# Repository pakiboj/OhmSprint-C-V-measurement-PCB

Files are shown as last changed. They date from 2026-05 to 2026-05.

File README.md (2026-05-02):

# OhmSprint-C-V-measurement-PCB

# SRB
PCB naprvljen za potrebe studentskog takmicenja OhmSprint organizovanog u aprilu 2026. godine. Bilo je potrebno napraviti uredjaj za merenje struje i napona radi estimiranja potrosnje, pa potom date podatke slati na neki nacin korisniku. 

Za potrebe projekta izabran je ESP32-C2 mikrokontroler a merenje struje i napona radjeno je preko ATM90E26 mernog cipa. Slanje podataka uradjeno je pomocu WROOM-C2 cipa ugradjenog sa ESP kontrolerom. 

# ENG
PCB designed for the needs of the student competition OhmSprint, organized in April 2026. The task was to build a device for measuring current and voltage in order to estimate power consumption, and then transmit the collected data to the user in some way.

For the purposes of the project, an ESP32-C2 microcontroller was chosen, and current and voltage measurements were performed via the ATM90E26 metering chip. Data transmission was implemented using the WROOM-C2 chip integrated with the ESP controller.

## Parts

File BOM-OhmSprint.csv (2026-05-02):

Reference | Qty | Exclude from BOM | Exclude from Board | Datasheet | Footprint | Value | MANUFACTURER | MPN | link
C1,C7,C8,C19,C26 | 5 |  |  | ~ | Capacitor_SMD:C_0603_1608Metric | 100n | NextGen Components | 0603B104K250SD | https://www.digikey.com/en/products/detail/nextgen-components/0603B104K250SD/22601930
C2 | 1 |  |  | ~ | Capacitor_SMD:C_0603_1608Metric | 22n | NextGen Components | 0603B223K500SD | https://www.digikey.com/en/products/detail/nextgen-components/0603B223K500SD/22601916
C3 | 1 |  |  |  | Capacitor_SMD:C_0805_2012Metric | 4.7uF | NextGen Components | 0805B475K250CC | https://www.digikey.com/en/products/detail/nextgen-components/0805B475K250CC/22601895
C4,C18 | 2 |  |  |  | Capacitor_SMD:C_0805_2012Metric | 0.1uF | NextGen Components | 0805B104J500BD | https://www.digikey.com/en/products/detail/nextgen-components/0805B104J500BD/22601900
C5,C11,C16,C25 | 4 |  |  | ~ | Capacitor_SMD:C_0805_2012Metric | 1u | Aillen | 0805B105K250CC | https://www.digikey.com/en/products/detail/nextgen-components/0805B105K250CC/22081490
C6 | 1 |  |  | ~ | Capacitor_SMD:C_0805_2012Metric | 220n | NextGen Components | 0805B224K500CC | https://www.digikey.com/en/products/detail/nextgen-components/0805B224K500CC/22601952
C9,C10 | 2 |  |  | ~ | Capacitor_SMD:C_0603_1608Metric | 20p | NextGen Components | 0603N200J500SD | https://www.digikey.com/en/products/detail/nextgen-components/0603N200J500SD/22601914
C15,C16-2,C20,C21 | 4 |  |  |  | Capacitor_SMD:C_0805_2012Metric | 33nF | NextGen Components | 0805B333K500BD | https://www.digikey.com/en/products/detail/nextgen-components/0805B333K500BD/22601891
C16-1,C17 | 2 |  |  |  | Capacitor_SMD:C_0603_1608Metric | 330nF | NextGen Components | 0805B334K500CC | https://www.digikey.com/en/products/detail/nextgen-components/0805B334K500CC/22601908
C22 | 1 |  |  |  | Capacitor_SMD:C_0805_2012Metric | 10uF | NextGen Components | 0805B334K500CC | https://www.digikey.com/en/products/detail/nextgen-components/0805B334K500CC/22601908
C23,C24 | 2 |  |  |  | Capacitor_SMD:C_0603_1608Metric | 0.1uF | NextGen Components | 0603B104K250SD | https://www.digikey.com/en/products/detail/nextgen-components/0603B104K250SD/22601930
D1,D2,D3 | 3 |  |  | ~ | Diode_SMD:D_1206_3216Metric | LED | XINGLIGHT | XL-3216SURC | https://www.digikey.com/en/products/detail/xinglight/XL-3216SURC/25673079
FB2 | 1 |  |  | ~ | Inductor_SMD:L_0805_2012Metric | 120R | Laird-Signal Integrity Products | LI0805H121R-10 | https://www.digikey.com/en/products/detail/laird-signal-integrity-products/LI0805H121R-10/806621
H1,H2,H3,H4 | 4 | Excluded from BOM |  | ~ | MountingHole:MountingHole_2mm | MountingHole
J1,J2,J4,J11,J12,J18 | 6 |  |  | ~ | Connector_AMASS:AMASS_XT30U-F_1x02_P5.0mm_Vertical | Conn_01x02_Pin | Sullins Connector Solutions | PRPC002SAAN-RC | https://www.digikey.com/en/products/detail/sullins-connector-solutions/PRPC002SAAN-RC/2775252
J3 | 1 |  |  |  | OhmSprint:CUI_PJ-002AH-SMT-TR | PJ-002AH-SMT-TR | Same Sky (Formerly CUI Devices) | PJ-002AH-SMT-TR | https://www.digikey.com/en/products/detail/same-sky-formerly-cui-devices/PJ-002AH-SMT-TR/408452
J5,J6,J19,J20 | 4 |  |  | ~ | Connector:FanPinHeader_1x04_P2.54mm_Vertical | Conn_01x04_Pin | Amphenol ICC (FCI) | 68002-404HLF | https://www.digikey.com/en/products/detail/amphenol-cs-fci/68002-404HLF/1878460
J7 | 1 |  |  | SJ-3523-SMT | OhmSprint:SJ-3523-SMT_CUD | SJ-3523-SMT | Same Sky (Formerly CUI Devices) | SJ-3523-SMT-TR | https://www.digikey.com/en/products/detail/same-sky-formerly-cui-devices/SJ-3523-SMT-TR/281297
J8 | 1 |  |  | USB_C_Receptacle_USB2.0_16P | Connector_USB:USB_C_Receptacle_GCT_USB4105-xx-A_16P_TopMnt_Horizontal | USB_C_Receptacle_USB2.0_16P | Same Sky (Formerly CUI Devices) | UJ20-C-H-G-SMT-TR | https://www.digikey.com/en/products/detail/same-sky-formerly-cui-devices/UJ20-C-H-G-SMT-TR/16629796
J9,J10,J13 | 3 |  |  | ~ | Connector:FanPinHeader_1x03_P2.54mm_Vertical | Conn_01x03_Pin | Amphenol ICC (FCI) | 68001-203HLF | https://www.digikey.com/en/products/detail/amphenol-cs-fci/68001-203HLF/2023312
J14,J15,J16,J17 | 4 |  |  | ~ | Connector_Hirose:Hirose_DF63M-1P-3.96DSA_1x01_P3.96mm_Vertical | Conn_01x01_Pin | Amphenol ICC (FCI) | 68000-101HLF | https://www.digikey.com/en/products/detail/amphenol-cs-fci/68000-101HLF/2023311
L2 | 1 |  |  | ~ | Inductor_SMD:L_0805_2012Metric | 4u7 | Coilcraft | 0805LS-222XJRC | https://www.digikey.com/en/products/detail/coilcraft/0805LS-222XJRC/15794577
R1,R10 | 2 |  |  | ~ | Resistor_SMD:R_0805_2012Metric | 5k1 | Bourns Inc. | CR0805-JW-512ELF | https://www.digikey.com/en/products/detail/bourns-inc/CR0805-JW-512ELF/3785337
R3,R5,R6 | 3 |  |  | ~ | Resistor_SMD:R_0805_2012Metric | 100R | Bourns Inc. | CR0805-FX-1000ELF | https://www.digikey.com/en/products/detail/bourns-inc/CR0805-FX-1000ELF/3740946
R3-1,R7,R16 | 3 |  |  | ~ | Resistor_SMD:R_0805_2012Metric | 10k | Bourns Inc. | CR0805-FX-1002ELF | https://www.digikey.com/en/products/detail/bourns-inc/CR0805-FX-1002ELF/3593209
R4,R17 | 2 |  |  | ~ | Resistor_SMD:R_0805_2012Metric | 1k5 | Bourns Inc. | CR0805-JW-152ELF | https://www.digikey.com/en/products/detail/bourns-inc/CR0805-JW-152ELF/3785240
R8,R9,R11,R15,R19,R20,R28 | 7 |  |  | ~ | Resistor_SMD:R_0805_2012Metric | 1k | Bourns Inc. | CR0805-FX-1001ELF | https://www.digikey.com/en/products/detail/bourns-inc/CR0805-FX-1001ELF/3593162
R12,R13,R14 | 3 |  |  |  | Resistor_SMD:R_0805_2012Metric | 4k | Bourns Inc. | CR0805-FX-4021ELF | https://www.digikey.com/en/products/detail/bourns-inc/CR0805-FX-4021ELF/3784926
R18 | 1 |  |  | ~ | Resistor_SMD:R_0805_2012Metric | 88k7 | Bourns Inc. | CR0805-FX-1001ELF | https://www.digikey.com/en/products/detail/bourns-inc/CR0805-FX-1001ELF/3593162
R21 | 1 |  |  |  | Resistor_SMD:R_0805_2012Metric | 51R | Bourns Inc. | CR0805-FX-51R0ELF | https://www.digikey.com/en/products/detail/bourns-inc/CR0805-FX-51R0ELF/3785003
R22,R23,RC1,RC2 | 4 |  |  |  | Resistor_SMD:R_0805_2012Metric | 2R4 | Bourns Inc. | CR0805-FX-2401ELF | https://www.digikey.com/en/products/detail/bourns-inc/CR0805-FX-2401ELF/3784778
R24 | 1 |  |  | ~ | Resistor_SMD:R_0805_2012Metric | 22k1 | Bourns Inc. | CR0805-FX-1001ELF | https://www.digikey.com/en/products/detail/bourns-inc/CR0805-FX-1001ELF/3593162
U1 | 1 |  |  | https://www.espressif.com/sites/default/files/documentation/esp32-c3-wroom-02_datasheet_en.pdf | RF_Module:ESP32-C3-WROOM-02 | ESP32-C3-WROOM-02 | Espressif Systems | ESP32-C3-WROOM-02-N4 | https://www.digikey.com/en/products/detail/espressif-systems/ESP32-C3-WROOM-02-N4/14553031
U2 | 1 |  |  | https://www.st.com/resource/en/datasheet/stth50w03c.pdf | OhmSprint:TO-247_15P75X5P1_STM | STTH50W03CW | STMicroelectronics | STTH50W03CW | https://www.digikey.com/en/products/detail/stmicroelectronics/STTH50W03CW/4552309
U3 | 1 |  |  |  | OhmSprint:SSOP28_10P3X5P4_MCH | ATM90E2x | Microchip Technology | ATM90E26-YU-R | https://www.digikey.de/en/products/detail/microchip-technology/ATM90E26-YU-R/4899918
U4 | 1 |  |  | https://www.ti.com/lit/gpn/lmr50410-q1 | DBV0006A-IPC_A | LMR50410Y5FQDBVRQ1 | Texas Instruments | LMR50410Y5FQDBVRQ1 | https://www.digikey.com/en/products/detail/texas-instruments/LMR50410Y5FQDBVRQ1/13563002
VR1 | 1 |  |  |  | OhmSprint:VREG_TS9011SCX_RFG | TS9011SCX_RFG | Taiwan Semiconductor | TS9011SCX RFG | https://www.digikey.com/en/products/detail/taiwan-semiconductor-corporation/TS9011SCX-RFG/7359865
X1 | 1 |  |  |  | OhmSprint:OSC_ECS-2520S25-250-FN-TR | 8.192MHz | ECS Inc. | XTAL OSC XO 8.192MHZ CMOS SMD | https://www.digikey.com/en/products/detail/ecs-inc/ECS-2520MVLC-081-92-CN-TR/16688217
Y1 | 1 |  |  | ~ | OhmSprint:OSC_ECS-2520S25-250-FN-TR | 32768Hz | ECS Inc. | XTAL OSC XO 32.7680KHZ SMD | https://www.digikey.com/en/products/detail/ecs-inc/ECS-327MVATX-2-CN-TR3/15282970

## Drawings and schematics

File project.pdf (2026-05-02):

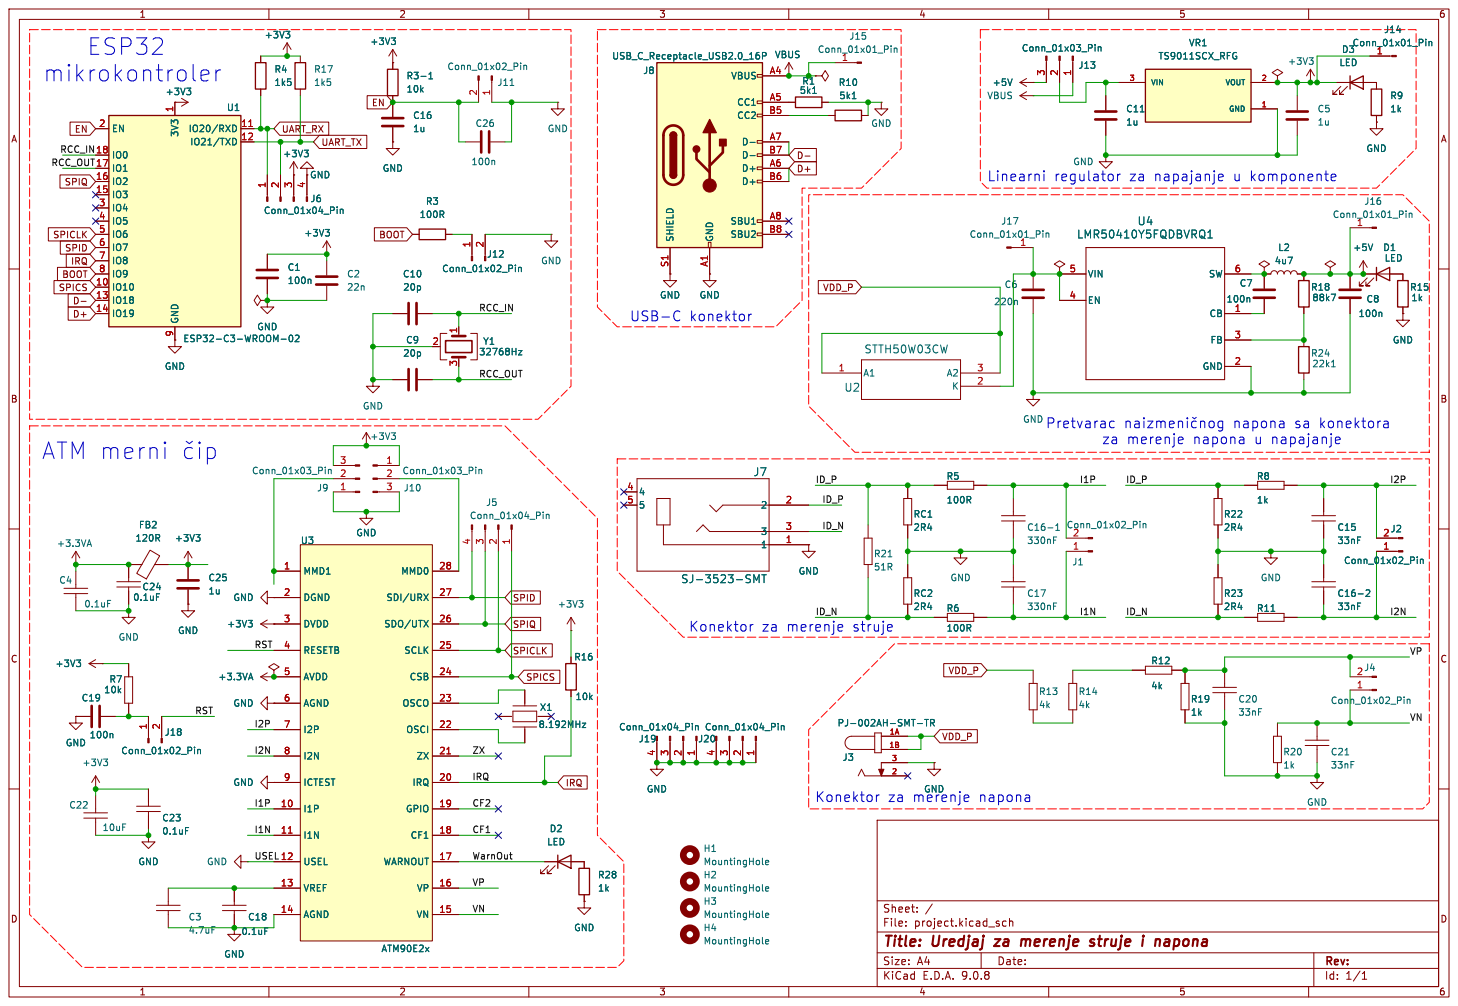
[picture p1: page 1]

za merenje napona u napajanje ATM merni þÿ

Konektor za merenje struje

Konektor za merenje napona

File: project.kicad_sch Sheet: /
Id: 1/1 Title: Uredjaj za merenje struje i napona

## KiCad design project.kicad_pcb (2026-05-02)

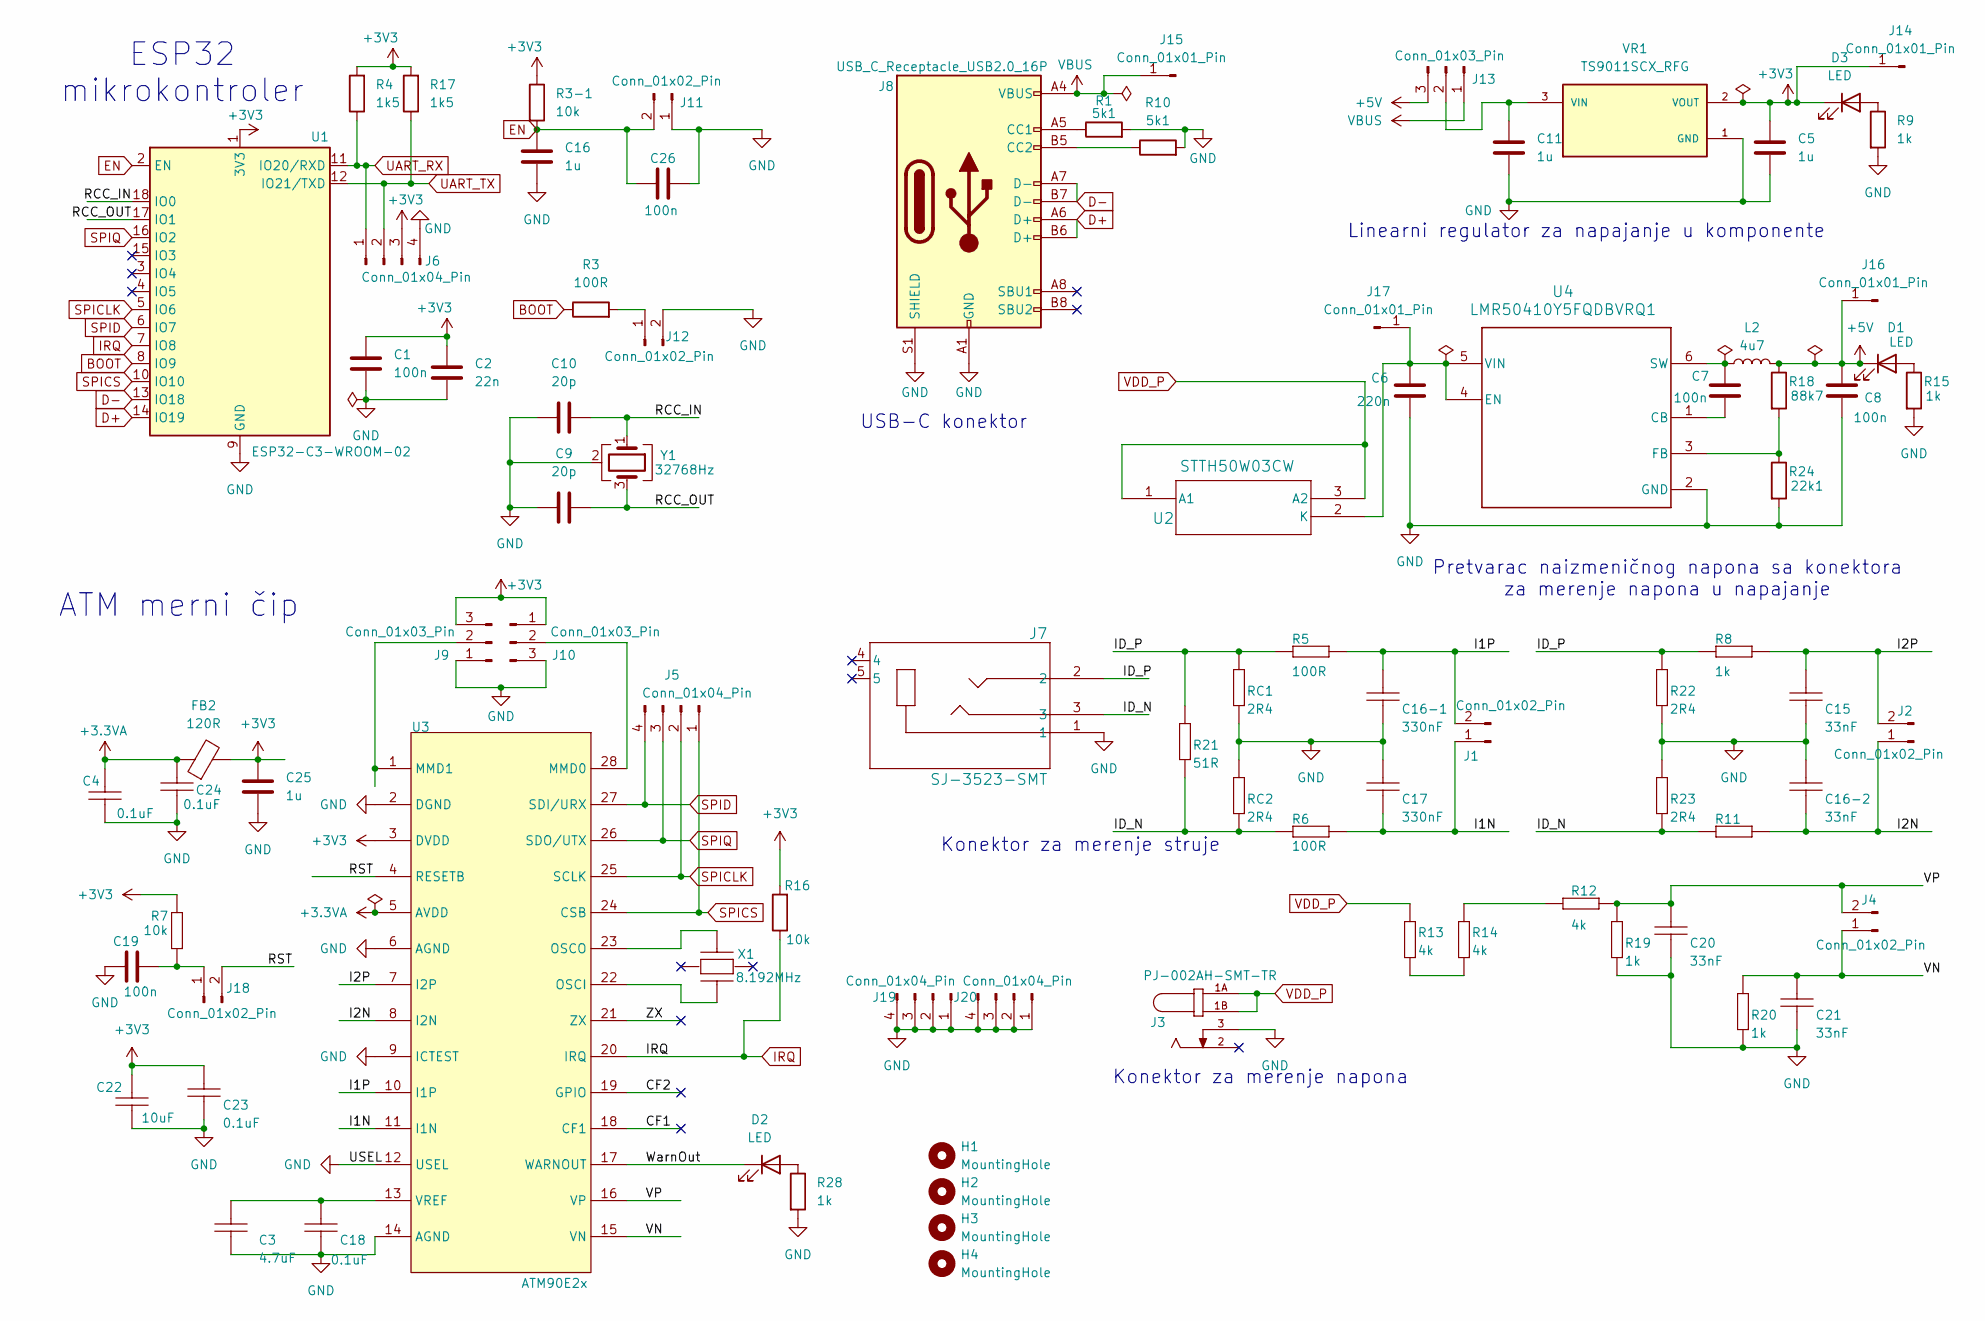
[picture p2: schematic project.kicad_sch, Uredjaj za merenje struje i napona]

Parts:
C1, C7, C8, C19, C26: 100n; C_0603_1608Metric; MPN 0603B104K250SD
C2: 22n; C_0603_1608Metric; MPN 0603B223K500SD
C3: 4.7uF; C_0805_2012Metric; MPN 0805B475K250CC
C4, C18: 0.1uF; C_0805_2012Metric; MPN 0805B104J500BD
C5, C11, C16, C25: 1u; C_0805_2012Metric; MPN 0805B105K250CC
C6: 220n; C_0805_2012Metric; MPN 0805B224K500CC
C9, C10: 20p; C_0603_1608Metric; MPN 0603N200J500SD
C15, C16-2, C20, C21: 33nF; C_0805_2012Metric; MPN 0805B333K500BD
C16-1, C17: 330nF; C_0603_1608Metric; MPN 0805B334K500CC
C22: 10uF; C_0805_2012Metric; MPN 0805B334K500CC
C23, C24: 0.1uF; C_0603_1608Metric; MPN 0603B104K250SD
D1, D2, D3: LED; D_1206_3216Metric; MPN XL-3216SURC
FB2: 120R; L_0805_2012Metric; MPN LI0805H121R-10
H1, H2, H3, H4: MountingHole; MountingHole_2mm
J1, J2, J4, J11, J12, J18: Conn_01x02_Pin; AMASS_XT30U-F_1x02_P5.0mm_Vertical; MPN PRPC002SAAN-RC
J3: PJ-002AH-SMT-TR; CUI_PJ-002AH-SMT-TR; MPN PJ-002AH-SMT-TR
J5, J6, J19, J20: Conn_01x04_Pin; FanPinHeader_1x04_P2.54mm_Vertical; MPN 68002-404HLF
J7: SJ-3523-SMT; SJ-3523-SMT_CUD; MPN SJ-3523-SMT-TR
J8: USB_C_Receptacle_USB2.0_16P; USB_C_Receptacle_GCT_USB4105-xx-A_16P_TopMnt_Horizontal; MPN UJ20-C-H-G-SMT-TR
J9, J10, J13: Conn_01x03_Pin; FanPinHeader_1x03_P2.54mm_Vertical; MPN 68001-203HLF
J14, J15, J16, J17: Conn_01x01_Pin; Hirose_DF63M-1P-3.96DSA_1x01_P3.96mm_Vertical; MPN 68000-101HLF
L2: 4u7; L_0805_2012Metric; MPN 0805LS-222XJRC
R1, R10: 5k1; R_0805_2012Metric; MPN CR0805-JW-512ELF
R3, R5, R6: 100R; R_0805_2012Metric; MPN CR0805-FX-1000ELF
R3-1, R7, R16: 10k; R_0805_2012Metric; MPN CR0805-FX-1002ELF
R4, R17: 1k5; R_0805_2012Metric; MPN CR0805-JW-152ELF
R8, R9, R11, R15, R19, R20, R28: 1k; R_0805_2012Metric; MPN CR0805-FX-1001ELF
R12, R13, R14: 4k; R_0805_2012Metric; MPN CR0805-FX-4021ELF
R18: 88k7; R_0805_2012Metric; MPN CR0805-FX-1001ELF
R21: 51R; R_0805_2012Metric; MPN CR0805-FX-51R0ELF
R22, R23: 2R4; R_0805_2012Metric; MPN CR0805-FX-2401ELF
R24: 22k1; R_0805_2012Metric; MPN CR0805-FX-1001ELF
RC1, RC2: 2R4; R_0805_2012Metric; MPN CR0805-FX-2401ELF
U1: ESP32-C3-WROOM-02; MPN ESP32-C3-WROOM-02-N4
U2: STTH50W03CW; TO-247_15P75X5P1_STM; MPN STTH50W03CW
U3: ATM90E2x; SSOP28_10P3X5P4_MCH; MPN ATM90E26-YU-R
U4: LMR50410Y5FQDBVRQ1; DBV0006A-IPC_C; MPN LMR50410Y5FQDBVRQ1
VR1: TS9011SCX_RFG; VREG_TS9011SCX_RFG; PARTREV I2402
X1: 8.192MHz; OSC_ECS-2520S25-250-FN-TR; MPN XTAL OSC XO 8.192MHZ CMOS SMD
Y1: 32768Hz; OSC_ECS-2520S25-250-FN-TR; MPN XTAL OSC XO 32.7680KHZ SMD

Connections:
+3.3VA: C4.2, C24.2, FB2.1, U3.5 (AVDD)
+3V3: C1.1, C2.1, C5.1, C22.1, C23.2, C25.1, D3.1 (K), FB2.2, J6.3, J9.3, J10.1, J14.1, R3-1.1, R4.2, R7.2, R16.2, R17.2, U1.1 (3V3), U3.3 (DVDD), VR1.2 (VOUT)
+5V: C8.1, D1.1 (K), J13.3, J16.1, L2.2, R18.1
/CF1: U3.18 (CF1)
/CF2: U3.19 (GPIO)
/I1N: C17.1, J1.1, R6.1, U3.11 (I1N)
/I1P: C16-1.2, J1.2, R5.1, U3.10 (I1P)
/I2N: C16-2.1, J2.1, R11.1, U3.8 (I2N)
/I2P: C15.2, J2.2, R8.1, U3.7 (I2P)
/ID_N: J7.3, R6.2, R11.2, R21.1, R23.1, RC2.1
/ID_P: J7.2, R5.2, R8.2, R21.2, R22.2, RC1.2
/RCC_IN: C10.2, U1.18 (IO0), Y1.1
/RCC_OUT: C9.2, U1.17 (IO1), Y1.3
/RST: J18.2, U3.4 (RESETB)
/VN: C21.2, J4.1, R20.2, U3.15 (VN)
/VP: C20.2, J4.2, R12.2, R19.2, U3.16 (VP)
/WarnOut: D2.1 (K), U3.17 (WARNOUT)
/ZX: U3.21 (ZX)
BOOT: R3.1, U1.8 (IO9)
D+: J8.A6 (D+), J8.B6 (D+), U1.14 (IO19)
D-: J8.A7 (D-), J8.B7 (D-), U1.13 (IO18)
EN: C16.1, C26.1, J11.2, R3-1.2, U1.2 (EN)
GND: C1.2, C2.2, C3.1, C4.1, C5.2, C6.2, C8.2, C9.1, C10.1, C11.2, C15.1, C16.2, C16-1.1, C16-2.2, C17.2, C18.1, C19.1, C20.1, C21.1, C22.2, C23.1, C24.1, C25.2, C26.2, J3.3, J6.4, J7.1, J8.A1 (GND), J8.A12 (GND), J8.B1 (GND), J8.B12 (GND), J8.S1 (SHIELD), J9.1, J10.3, J11.1, J12.2, J19.1, J19.2, J19.3, J19.4, J20.1, J20.2, J20.3, J20.4, R1.2, R9.2, R10.2, R15.2, R19.1, R20.1, R22.1, R23.2, R24.2, R28.2, RC1.1, RC2.2, U1.9 (GND), U1.19 (GND), U3.2 (DGND), U3.6 (AGND), U3.9 (ICTEST), U3.12 (USEL), U3.14 (AGND), U4.2 (GND), VR1.1 (GND), Y1.2 (G), Y1.4 (G)
IRQ: R16.1, U1.7 (IO8), U3.20 (IRQ)
unnamed: D1.2 (A), R15.1
unnamed: D2.2 (A), R28.1
unnamed: D3.2 (A), R9.1
unnamed: J8.A5 (CC1), R1.1
unnamed: J8.B5 (CC2), R10.1
unnamed: J9.2, U3.1 (MMD1)
unnamed: J10.2, U3.28 (MMD0)
unnamed: J12.1, R3.2
unnamed: C11.1, J13.2, VR1.3 (VIN)
unnamed: C6.1, J17.1, U2.2 (K), U4.4 (EN), U4.5 (VIN)
unnamed: C19.2, J18.1, R7.1
unnamed: R12.1, R14.1
unnamed: R13.2, R14.2
unnamed: U3.22 (OSCI), X1.2
unnamed: U3.23 (OSCO), X1.1
unnamed: C3.2, C18.2, U3.13 (VREF)
unnamed: C7.2, U4.1 (CB)
unnamed: R18.2, R24.1, U4.3 (FB)
unnamed: C7.1, L2.1, U4.6 (SW)
SPICLK: J5.2, U1.5 (IO6), U3.25 (SCLK)
SPICS: J5.1, U1.10 (IO10), U3.24 (CSB)
SPID: J5.4, U1.6 (IO7), U3.27 (SDI/URX)
SPIQ: J5.3, U1.16 (IO2), U3.26 (SDO/UTX)
UART_RX: J6.1, R4.1, U1.11 (IO20/RXD)
UART_TX: J6.2, R17.1, U1.12 (IO21/TXD)
VBUS: J8.A4 (VBUS), J8.A9 (VBUS), J8.B4 (VBUS), J8.B9 (VBUS), J13.1, J15.1
VDD_P: J3.1A, J3.1B, R13.1, U2.1 (A1), U2.3 (A2)

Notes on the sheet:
ATM merni čip
USB-C konektor
Konektor za merenje struje
ESP32 mikrokontroler
Konektor za merenje napona
Linearni regulator za napajanje u komponente
Pretvarac naizmeničnog napona sa konektora za merenje napona u napajanje

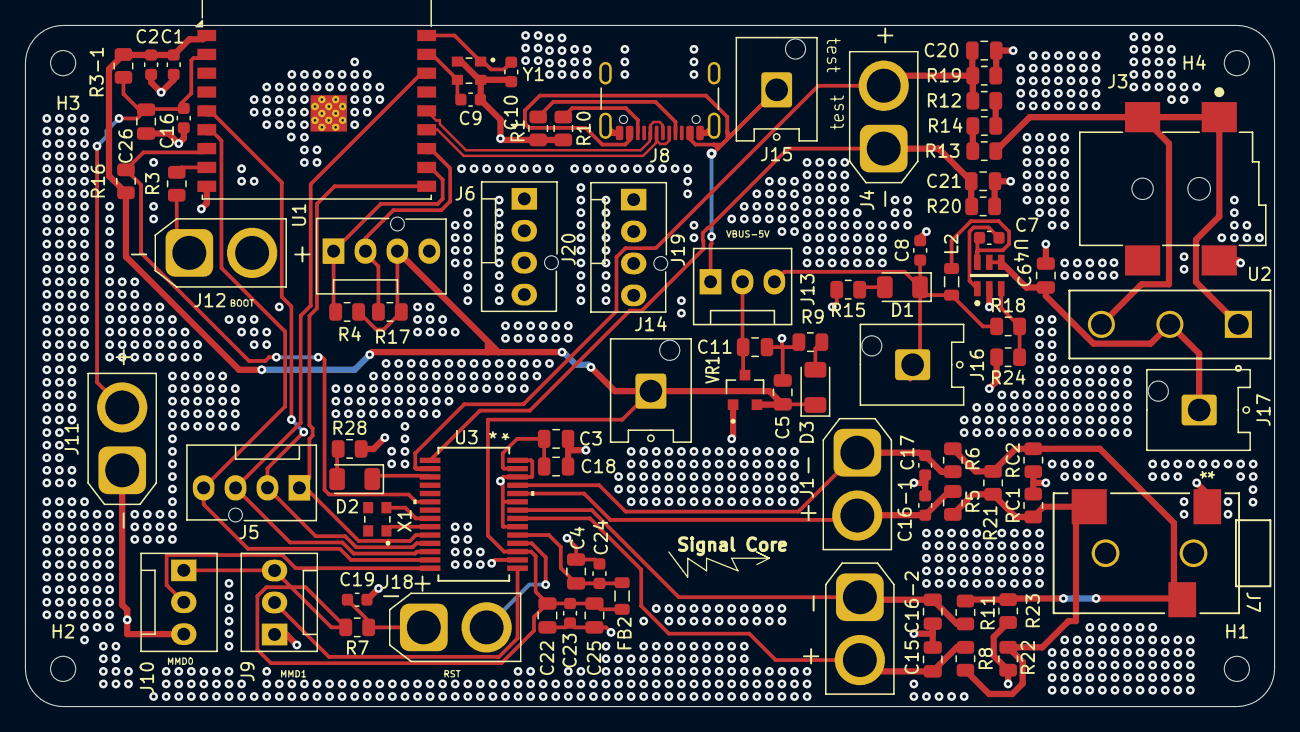
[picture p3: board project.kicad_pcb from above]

Board: 2 copper layers, 99.4 x 54.2 mm, 88 parts (0 on the bottom side), 48 nets.
